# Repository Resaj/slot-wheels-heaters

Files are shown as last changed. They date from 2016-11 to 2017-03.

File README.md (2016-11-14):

# Slot wheels heaters
Wheels heaters for slot cars or line-following robots.

Each wheel heater carries a thermistor and is composed of an array of 25 resistor in parallel. The value of each resistance is 470 Ohm and the supply is a lipo battery 2S. Changing this values may burn the heaters, so if you change the values be sure the power consume values are right.

<p align="center">
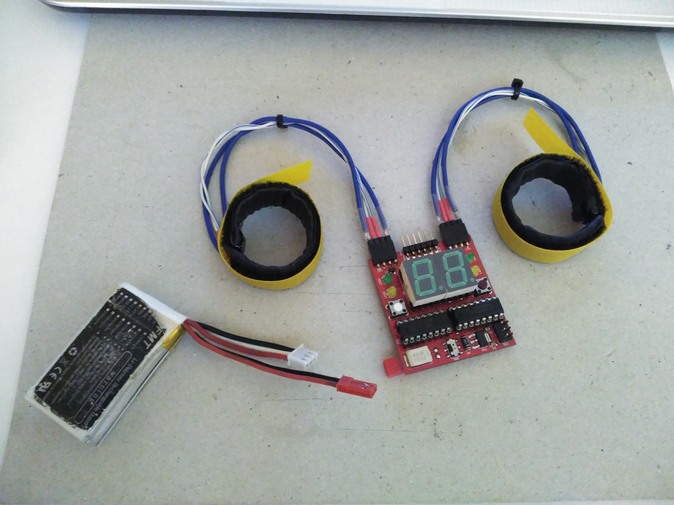
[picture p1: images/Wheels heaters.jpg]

</p>

## Author
[Rubén Espino San José](https://github.com/Resaj)

## License
<p align="center">

</p>

Todos estos productos están liberados mediante [Creative Commons Attribution-ShareAlike 4.0 International License](http://creativecommons.org/licenses/by-sa/4.0/).  
_All these products are released under [Creative Commons Attribution-ShareAlike 4.0 International License](http://creativecommons.org/licenses/by-sa/4.0/)._

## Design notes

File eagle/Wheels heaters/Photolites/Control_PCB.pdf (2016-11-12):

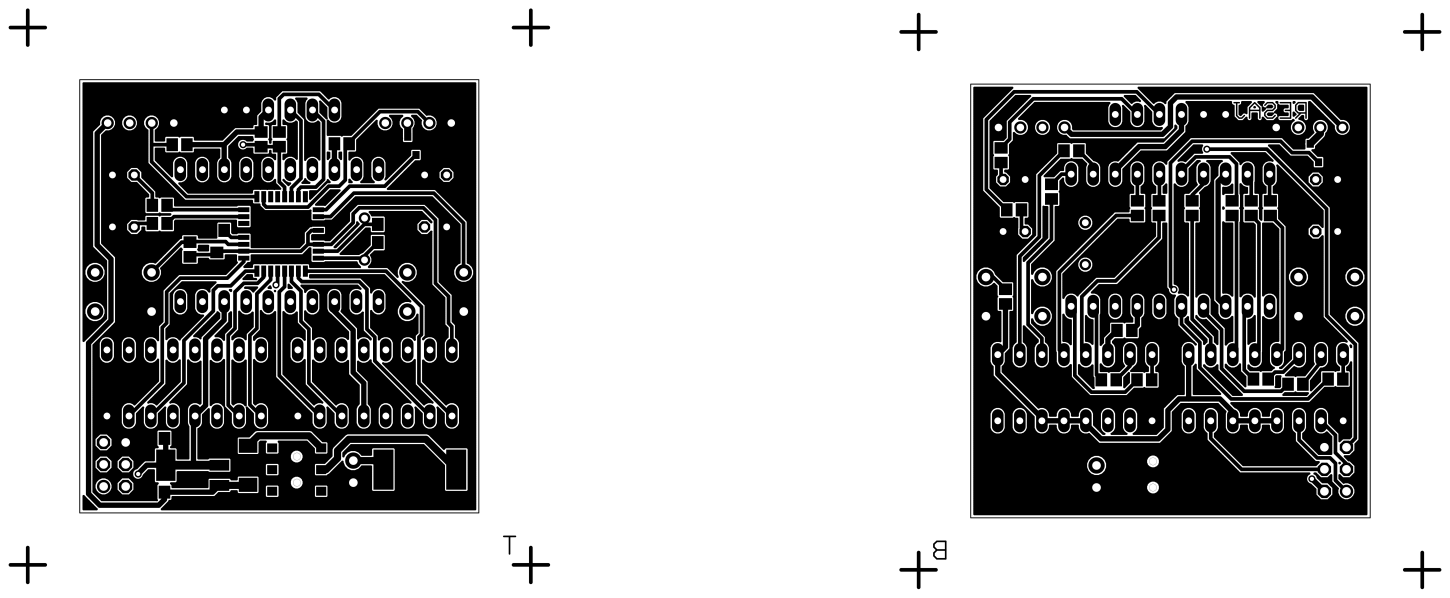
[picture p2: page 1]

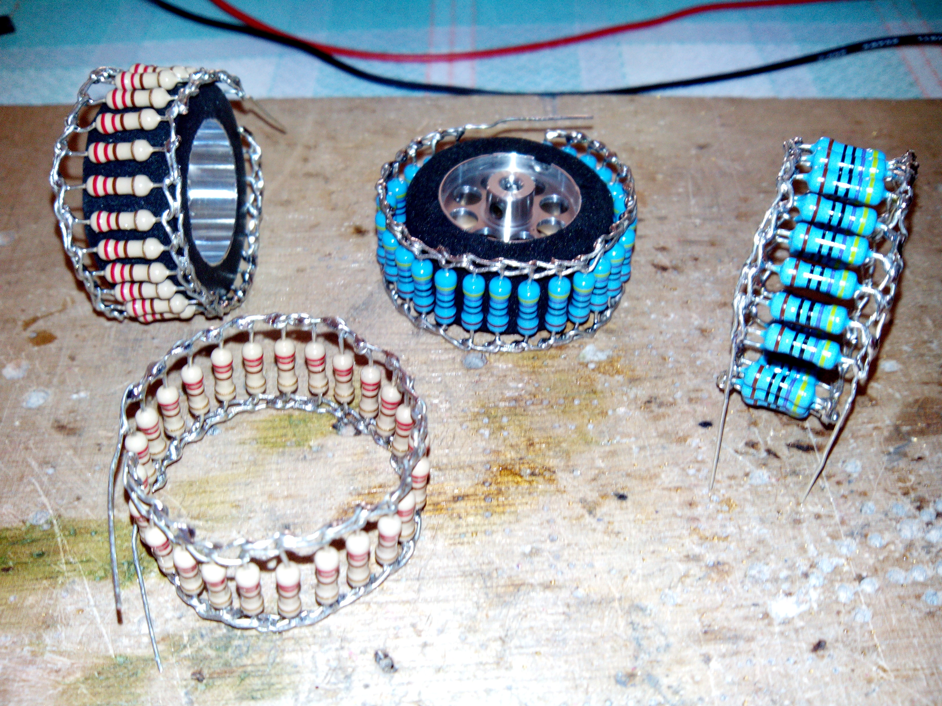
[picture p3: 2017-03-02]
images/IMG-20140706-WA0007.jpg

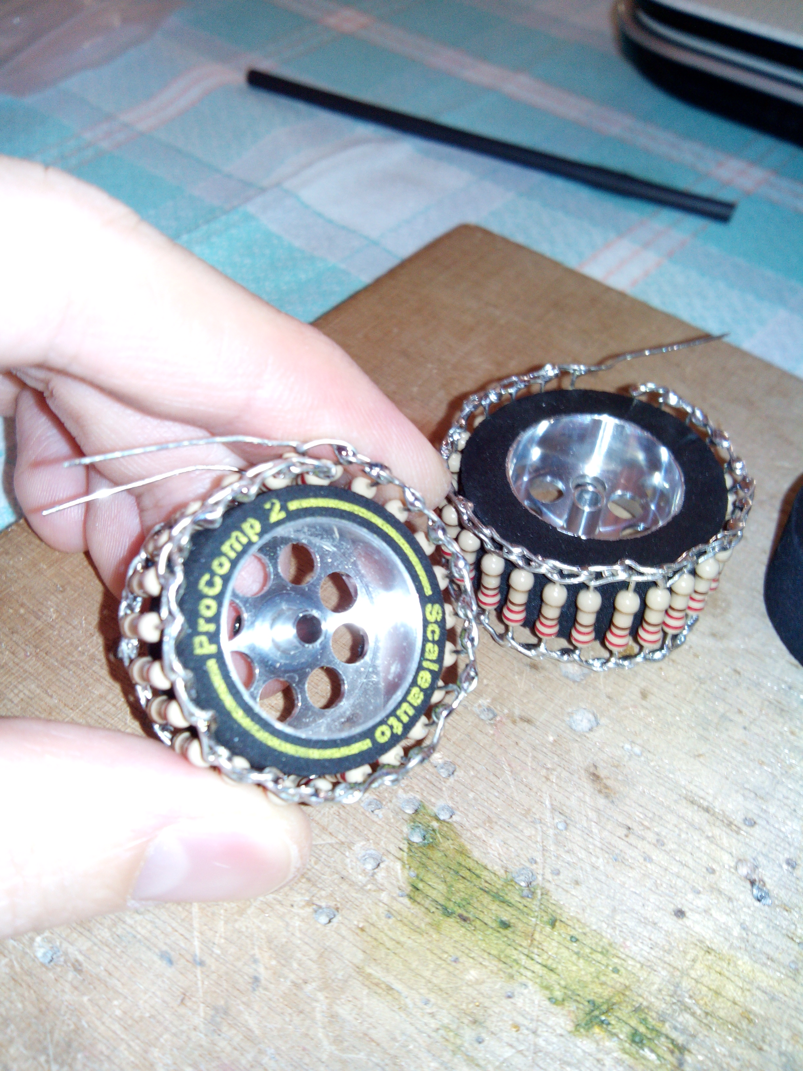
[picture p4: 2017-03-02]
images/IMG-20140706-WA0009.jpg

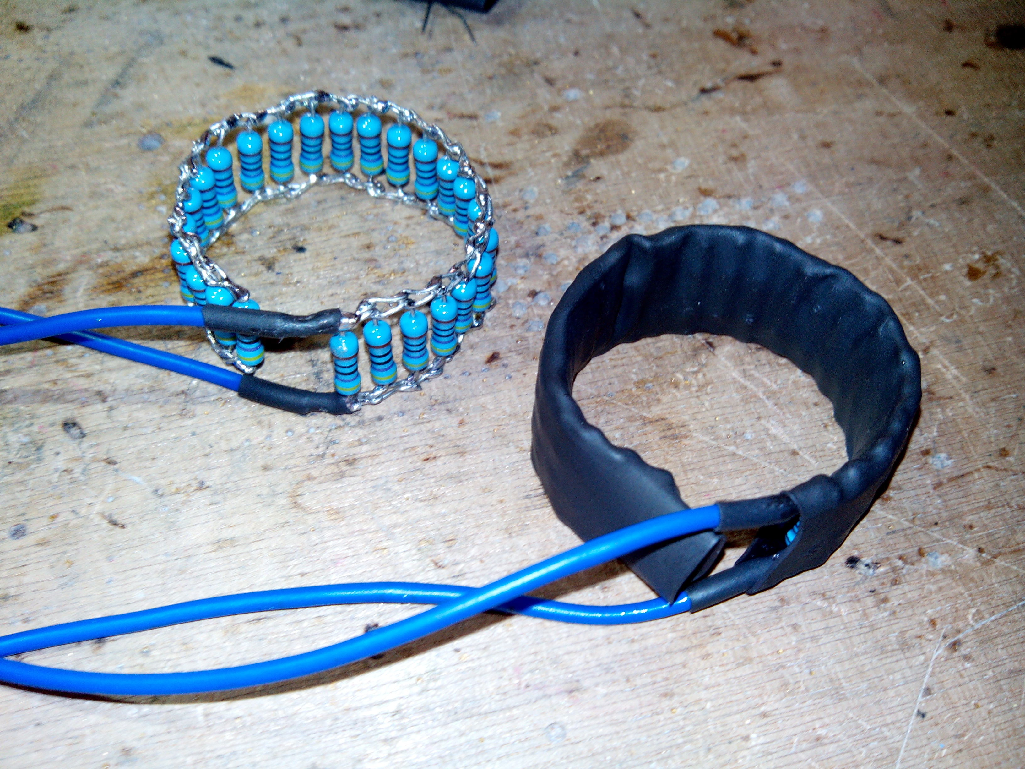
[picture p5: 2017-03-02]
images/IMG-20140706-WA0013.jpg

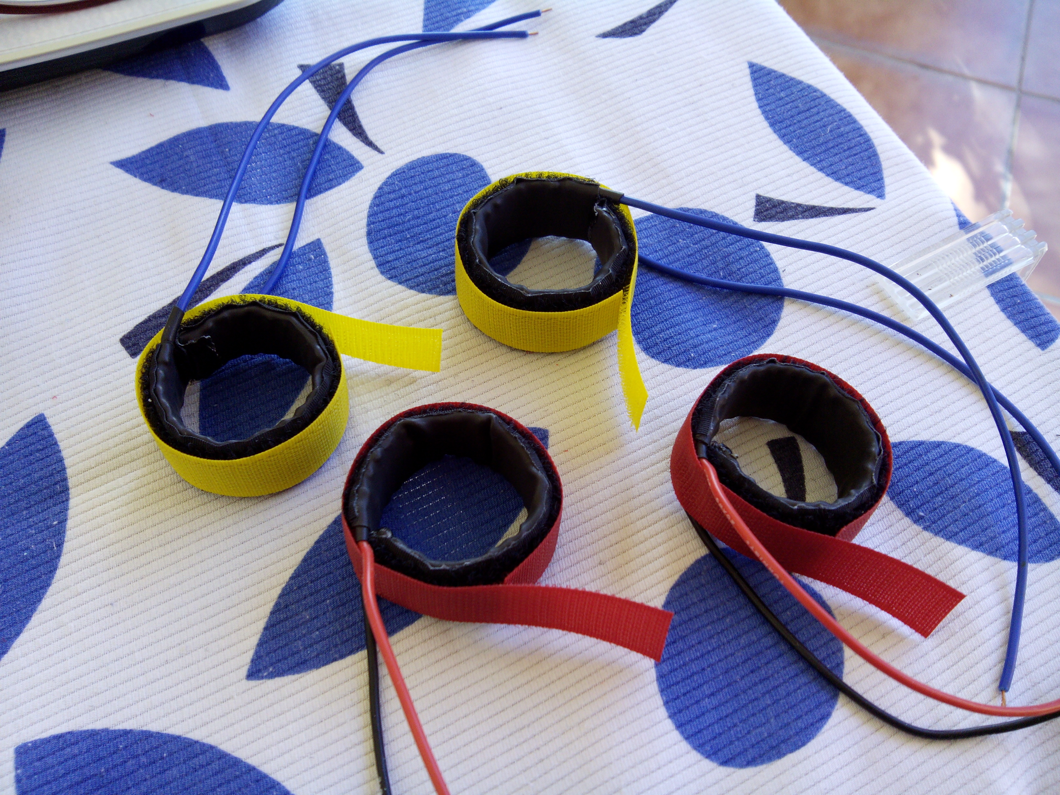
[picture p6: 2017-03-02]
images/IMG-20140808-WA0012.jpg

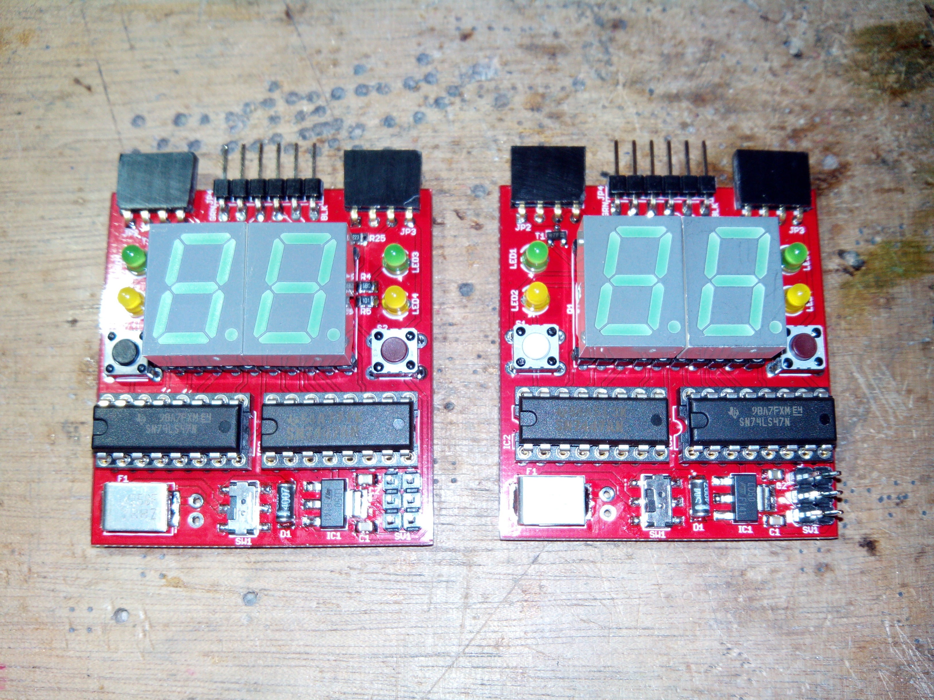
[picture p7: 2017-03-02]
images/IMG-20140826-WA0004.jpg

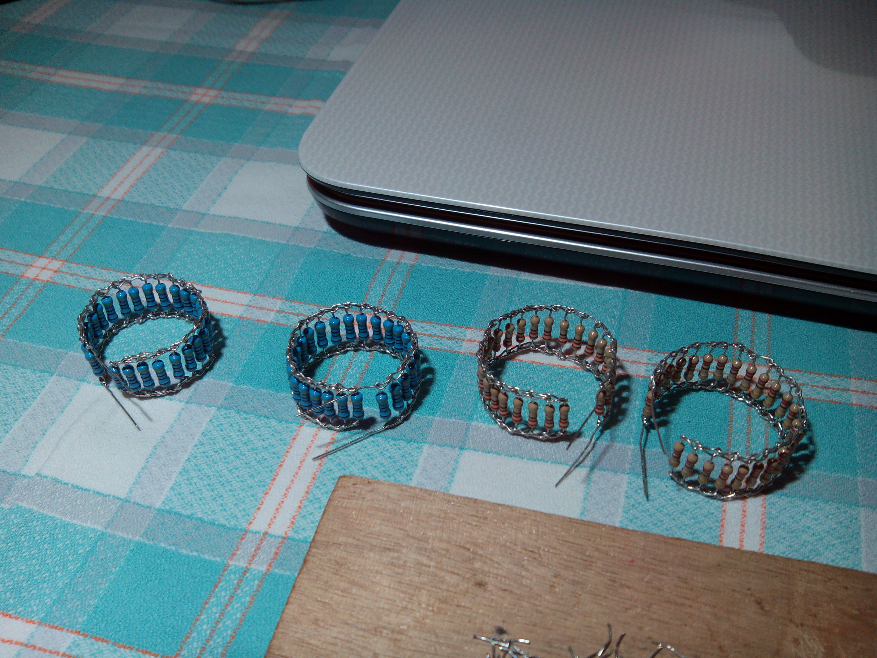
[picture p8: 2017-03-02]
images/IMG-20140706-WA0005.jpg

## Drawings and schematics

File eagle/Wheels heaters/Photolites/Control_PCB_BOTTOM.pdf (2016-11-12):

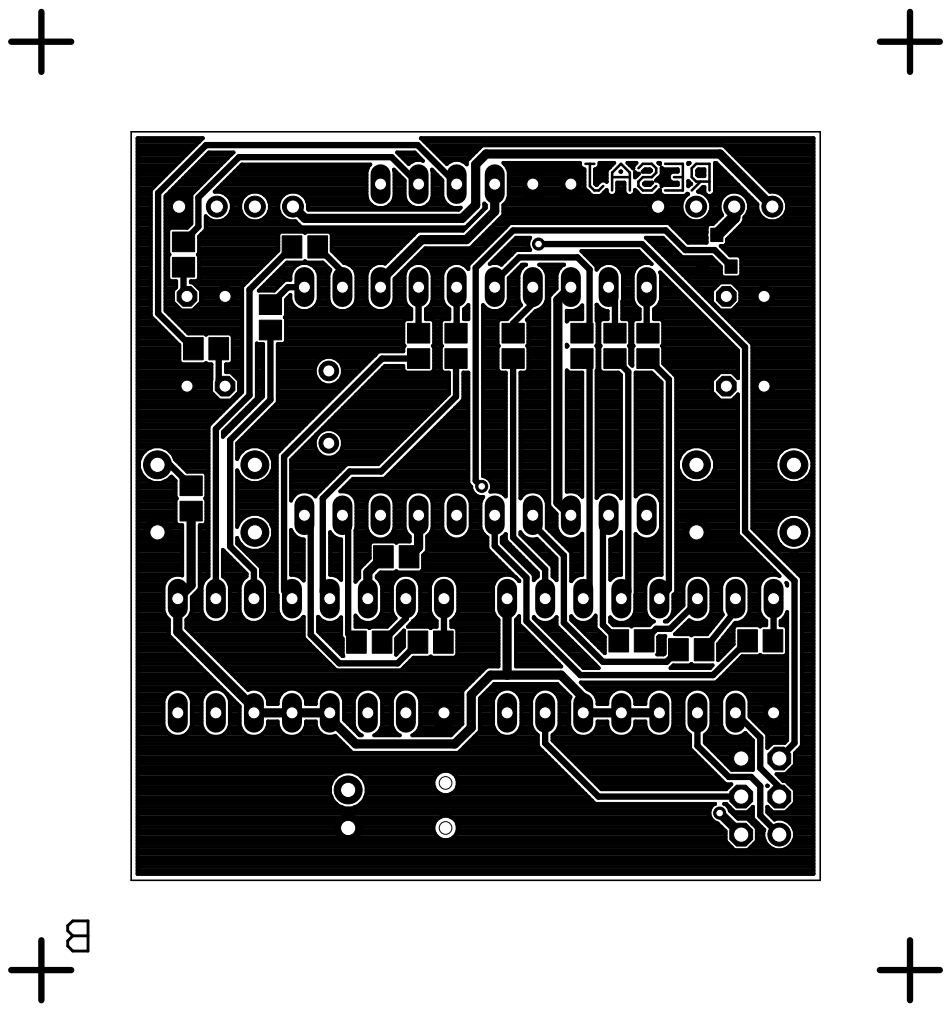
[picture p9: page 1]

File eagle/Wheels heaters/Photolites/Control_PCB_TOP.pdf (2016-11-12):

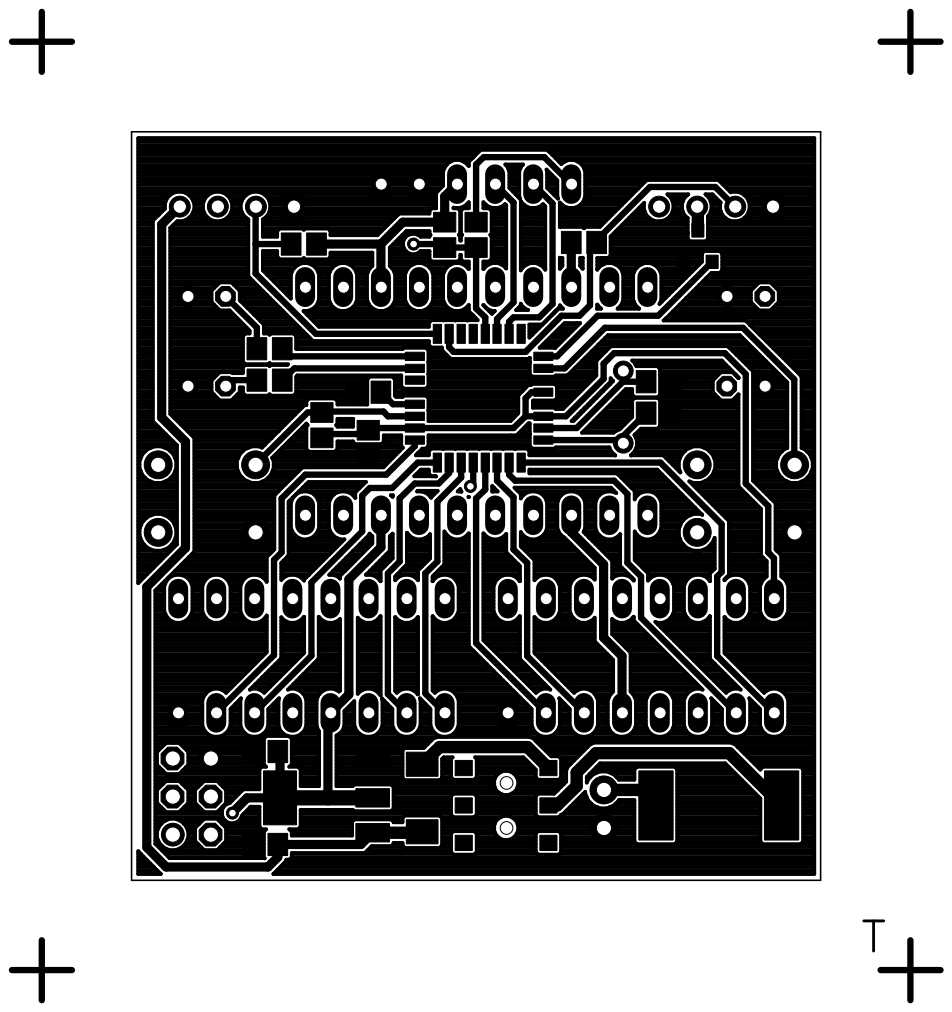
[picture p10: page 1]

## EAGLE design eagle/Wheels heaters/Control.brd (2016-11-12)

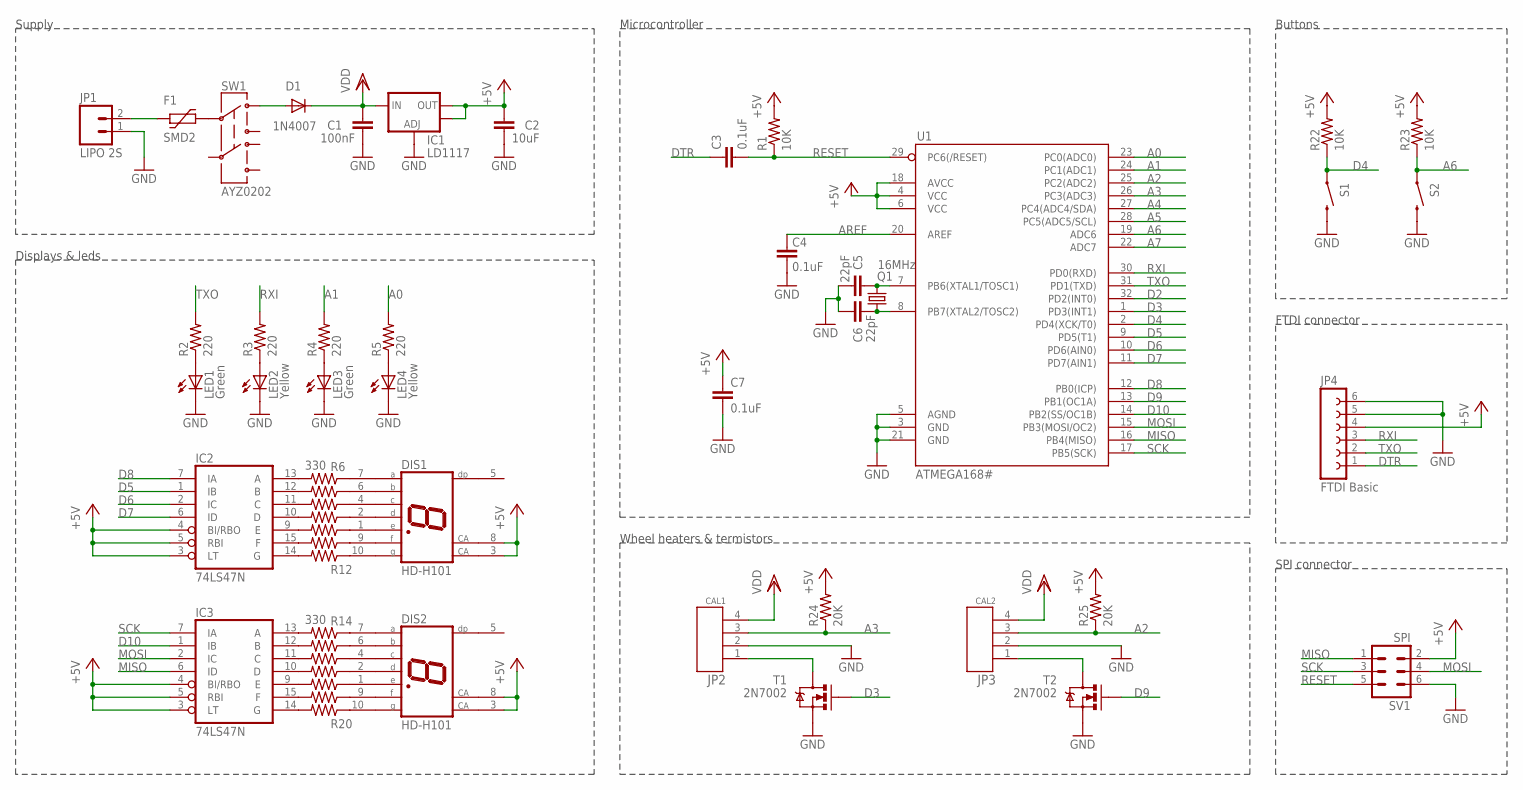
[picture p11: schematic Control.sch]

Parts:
C1: 100nF; C0805
C2: 10uF; C0805
C3, C4, C7: 0.1uF; C0805
C5, C6: 22pF; C0805
D1: 1N4007; SOD106-R
DIS1, DIS2: HD-H101; HDSP-M
F1: SMD2
IC1: LD1117; SOT223
IC2, IC3: 74LS47N; DIL16
JP1: LIPO 2S; 1X02
JP2: CAL1; 4_PINES_MACHO_TUMBADOS
JP3: CAL2; 4_PINES_MACHO_TUMBADOS
JP4: FTDI Basic; FE06W
LED1, LED3: Green; LED3MM
LED2, LED4: Yellow; LED3MM
Q1: 16MHz; HC49/S
R1, R22, R23: 10K; R0805
R2, R3, R4, R5: 220; R0805
R6, R7, R8, R9, R10, R11, R12, R14, R15, R16, R17, R18, R19, R20: 330; R0805
R24, R25: 20K; R0805
S1, S2: SWITCH-MOMENTARY-2PTH; TACTILE-PTH
SV1: SPI; MA03-2
SW1: AYZ0202
T1, T2: 2N7002; SOT23-3
U1: ATMEGA168#; TQFP32-08

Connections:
+5V: C2.1, C7.1, DIS1.3 (CA), DIS1.8 (CA), DIS2.3 (CA), DIS2.8 (CA), IC1.2 (OUT), IC1.4 (OUT), IC2.3 (LT), IC2.4 (BI/RBO), IC2.5 (RBI), IC2.16 (VCC), IC3.3 (LT), IC3.4 (BI/RBO), IC3.5 (RBI), IC3.16 (VCC), JP4.4, R1.2, R22.2, R23.2, R24.2, R25.2, SV1.2, U1.4 (VCC), U1.6 (VCC), U1.18 (AVCC)
A0: R5.2, U1.23 (PC0(ADC0))
A1: R4.2, U1.24 (PC1(ADC1))
A2: JP3.3, R25.1, U1.25 (PC2(ADC2))
A3: JP2.3, R24.1, U1.26 (PC3(ADC3))
A4: U1.27 (PC4(ADC4/SDA))
A5: U1.28 (PC5(ADC5/SCL))
A6: R23.1, S2.1, U1.19 (ADC6)
A7: U1.22 (ADC7)
AREF: C4.2, U1.20 (AREF)
D2: U1.32 (PD2(INT0))
D3: T1.1 (G), U1.1 (PD3(INT1))
D4: R22.1, S1.1, U1.2 (PD4(XCK/T0))
D5: IC2.1 (IB), U1.9 (PD5(T1))
D6: IC2.2 (IC), U1.10 (PD6(AIN0))
D7: IC2.6 (ID), U1.11 (PD7(AIN1))
D8: IC2.7 (IA), U1.12 (PB0(ICP))
D9: T2.1 (G), U1.13 (PB1(OC1A))
D10: IC3.1 (IB), U1.14 (PB2(SS/OC1B))
DTR: C3.1, JP4.1
GND: C1.1, C2.2, C4.1, C5.1, C6.1, C7.2, IC1.1 (ADJ), IC2.8 (GND), IC3.8 (GND), JP1.1, JP2.2, JP3.2, JP4.5, JP4.6, LED1.K (C), LED2.K (C), LED3.K (C), LED4.K (C), S1.3 (2), S2.3 (2), SV1.6, T1.2 (S), T2.2 (S), U1.3 (GND), U1.5 (AGND), U1.21 (GND)
MISO: IC3.6 (ID), SV1.1, U1.16 (PB4(MISO))
MOSI: IC3.2 (IC), SV1.4, U1.15 (PB3(MOSI/OC2))
unnamed: C6.2, Q1.2, U1.8 (PB7(XTAL2/TOSC2))
unnamed: C5.2, Q1.1, U1.7 (PB6(XTAL1/TOSC1))
unnamed: JP2.1, T1.3 (D)
unnamed: JP3.1, T2.3 (D)
unnamed: LED2.A, R3.1
unnamed: LED3.A, R4.1
unnamed: D1.A, SW1.3 (1)
unnamed: F1.P$2 (2), SW1.2
unnamed: F1.P$1 (1), JP1.2
unnamed: LED4.A, R5.1
unnamed: LED1.A, R2.1
unnamed: IC2.13 (A), R6.2
unnamed: DIS1.7 (A), R6.1
unnamed: IC2.12 (B), R7.2
unnamed: DIS1.6 (B), R7.1
unnamed: IC2.11 (C), R8.2
unnamed: DIS1.4 (C), R8.1
unnamed: IC2.10 (D), R9.2
unnamed: DIS1.2 (D), R9.1
unnamed: IC2.9 (E), R10.2
unnamed: DIS1.1 (E), R10.1
unnamed: IC2.15 (F), R11.2
unnamed: DIS1.9 (F), R11.1
unnamed: IC2.14 (G), R12.2
unnamed: DIS1.10 (G), R12.1
unnamed: IC3.13 (A), R14.2
unnamed: DIS2.7 (A), R14.1
unnamed: IC3.12 (B), R15.2
unnamed: DIS2.6 (B), R15.1
unnamed: IC3.11 (C), R16.2
unnamed: DIS2.4 (C), R16.1
unnamed: IC3.10 (D), R17.2
unnamed: DIS2.2 (D), R17.1
unnamed: IC3.9 (E), R18.2
unnamed: DIS2.1 (E), R18.1
unnamed: IC3.15 (F), R19.2
unnamed: DIS2.9 (F), R19.1
unnamed: IC3.14 (G), R20.2
unnamed: DIS2.10 (G), R20.1
RESET: C3.2, R1.1, SV1.5, U1.29 (PC6(/RESET))
RXI: JP4.3, R3.2, U1.30 (PD0(RXD))
SCK: IC3.7 (IA), SV1.3, U1.17 (PB5(SCK))
TXO: JP4.2, R2.2, U1.31 (PD1(TXD))
VDD: C1.2, D1.C, IC1.3 (IN), JP2.4, JP3.4

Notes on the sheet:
FTDI connector
Microcontroller
Displays & leds
Wheel heaters & termistors
Supply
Buttons
SPI connector

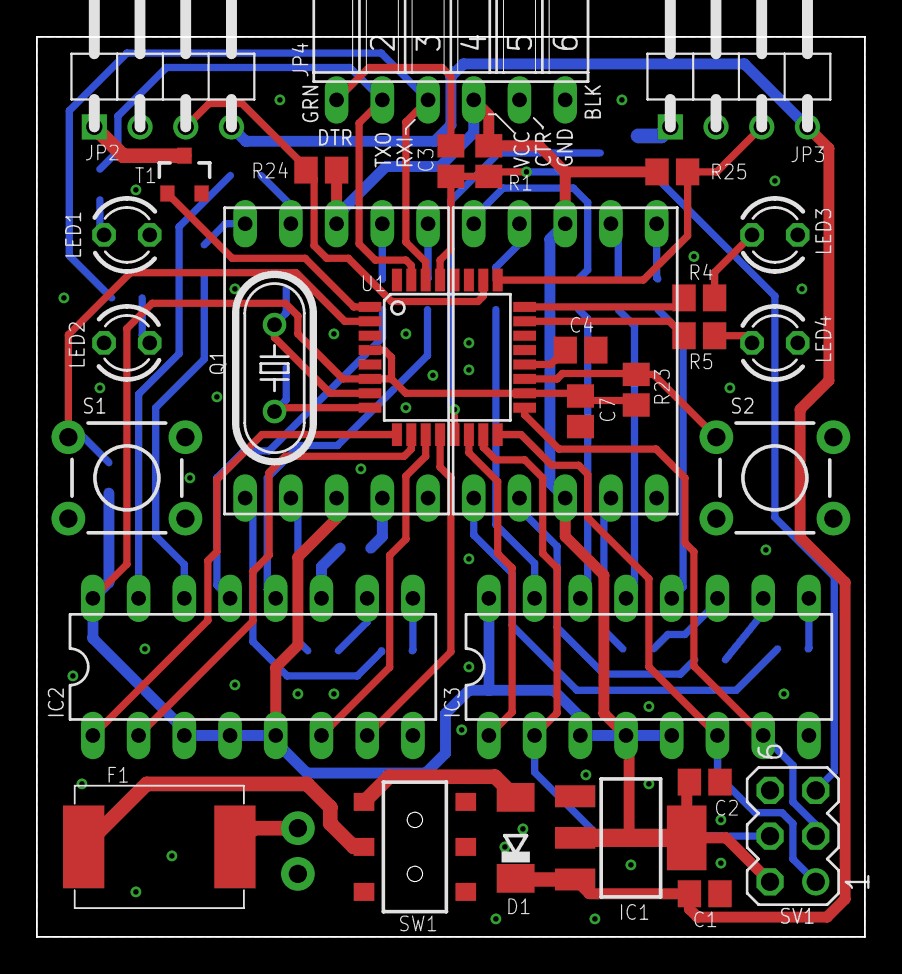
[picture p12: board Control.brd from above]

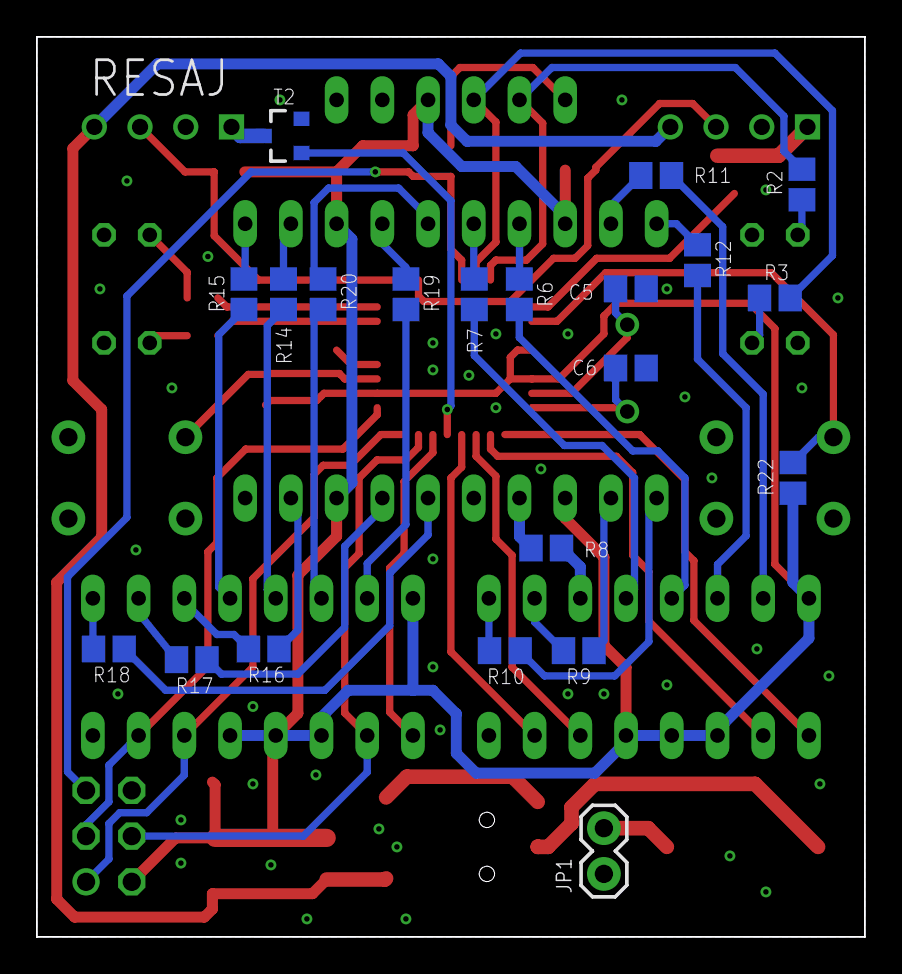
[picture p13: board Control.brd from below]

Board: 2 copper layers, 46.0 x 50.0 mm, 53 parts (21 on the bottom side), 63 nets.

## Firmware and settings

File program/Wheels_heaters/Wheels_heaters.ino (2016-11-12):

//#define SERIAL_ENABLE

int period = 10; // ms
int cont = 0;
int cont2 = 0;
int cont3 = 0;
int state = 0;

const int button_L = 4;
const int button_R = A6;
int button_L_State = 0;
int button_R_State = 0;
int button_L_State_ant = 0;
int button_R_State_ant = 0;

const int led_L_green =  1;
const int led_L_yellow =  0;
const int led_R_green =  A1;
const int led_R_yellow =  A0;

const int display1_A =  8;
const int display1_B =  5;
const int display1_C =  6;
const int display1_D =  7;
const int display2_A =  13;
const int display2_B =  10;
const int display2_C =  11;
const int display2_D =  12;

const int heater_L = 3;
const int heater_R = 9;

const int Tsensor_L = A3;
const int Tsensor_R = A2;
float bit_T_L = 0, bit_T_R = 0;
float T_L = 0, T_R = 0;
int T = 0;
int T_min = 0;
int T_max = 80;
float p_L = 0, p_R = 0;
float last_p_L = 0, last_p_R = 0;
float i_L = 0, i_R = 0;
float limit_int = 180;
float d_L = 0, d_R = 0;
float kp = 1000;
float ki = 0;
float kd = 0;
float controlT_L = 0;
float controlT_R = 0;
float Pmax = 255; // Máximum PWM output for transistors (between 0 & 255)

const int OVERSAMPLENR = 3;

const float temptable[][2] = {
   {1, 713},
   {17, 300},
   {20, 290},
   {23, 280},
   {27, 270},
   {31, 260},
   {37, 250},
   {43, 240},
   {51, 230},
   {61, 220},
   {73, 210},
   {87, 200},
   {106, 190},
   {128, 180},
   {155, 170},
   {189, 160},
   {230, 150},
   {278, 140},
   {336, 130},
   {402, 120},
   {476, 110},
   {554, 100},
   {635, 90},
   {713, 80},
   {784, 70},
   {846, 60},
   {897, 50},
   {937, 40},
   {966, 30},
   {986, 20},
   {1000, 10},
   {1010, 0}
};

void setup() {
  pinMode(button_L, INPUT);      
//  pinMode(button_R, INPUT);  // analog read of button_R

#ifndef SERIAL_ENABLE
  pinMode(led_L_green, OUTPUT);
  pinMode(led_L_yellow, OUTPUT);
  pinMode(led_R_green, OUTPUT);
  pinMode(led_R_yellow, OUTPUT);
#endif

  pinMode(display1_A, OUTPUT);
  pinMode(display1_B, OUTPUT);
  pinMode(display1_C, OUTPUT);
  pinMode(display1_D, OUTPUT);
  pinMode(display2_A, OUTPUT);
  pinMode(display2_B, OUTPUT);
  pinMode(display2_C, OUTPUT);
  pinMode(display2_D, OUTPUT);

#ifdef SERIAL_ENABLE
  Serial.begin(9600); 
#endif
}

void loop() {
/******************************* BUTTONS READING *******************************/
  button_L_State = digitalRead(button_L);
  button_R_State = analogRead(button_R);
  if(button_R_State > 512)
    button_R_State = HIGH;
  else
    button_R_State = LOW;

  if(button_L_State == LOW && button_L_State_ant == HIGH && T > T_min)
  {
    T = T - 5;
    state = 1;
    cont = 0;
  }
  else if(button_R_State == LOW && button_R_State_ant == HIGH && T < T_max)
  {
    T = T + 5;
    state = 1;
    cont = 0;
  }
  
  button_L_State_ant = button_L_State;
  button_R_State_ant = button_R_State;

  if(cont3 >= 500)
  {
/******************************* READING AND AVERAGE TEMPERATURE *******************************/
    bit_T_L = 0;
    bit_T_R = 0;
    for(int i=0; i<OVERSAMPLENR; i++)
    {
      bit_T_L = bit_T_L + analogRead(Tsensor_L);
      bit_T_R = bit_T_R + analogRead(Tsensor_R);
    }
    bit_T_L = bit_T_L/OVERSAMPLENR;
    bit_T_R = bit_T_R/OVERSAMPLENR;

    T_L = bit2deg(bit_T_L);
    T_R = bit2deg(bit_T_R);
  
/******************************* TEMPERATURE PID *******************************/
    p_L = T - T_L;
    p_R = T - T_R;
  
    d_L = p_L - last_p_L;
    d_R = p_R - last_p_R;
  
    i_L = i_L + p_L;
    i_R = i_R + p_R;
    
    if(i_L > limit_int)
      i_L = limit_int;
    if(i_R > limit_int)
      i_R = limit_int;
  
    last_p_L = p_L;
    last_p_R = p_R;
    
    controlT_L = p_L * kp + i_L * ki + d_L * kd;
    controlT_R = p_R * kp + i_R * ki + d_R * kd;
  
    if(controlT_L > Pmax)
      controlT_L = Pmax;
    else if(controlT_L < 0)
      controlT_L = 0;
    if(controlT_R > Pmax)
      controlT_R = Pmax;
    else if(controlT_R < 0)
      controlT_R = 0;
  
    analogWrite(heater_L, controlT_L);           
    analogWrite(heater_R, controlT_R);
  }

/******************************* LEDS AND DISPLAY *******************************/
  if(abs(T - T_L) < 2)
    writeLED(led_L_green, HIGH);
  else
    writeLED(led_L_green, LOW);
  if(abs(T - T_R) < 2)
    writeLED(led_R_green, HIGH);
  else
    writeLED(led_R_green, LOW);

  if(state == 0)
  {
    if(cont < 1000)
    {
      writeLED(led_L_yellow, LOW);
      writeLED(led_R_yellow, LOW);
      display_T(int(T));
    }
    else if(cont < 2000)
    {
      writeLED(led_L_yellow, HIGH);
      writeLED(led_R_yellow, LOW);
      display_T(int(T_L));
    }
    else
    {
      writeLED(led_L_yellow, LOW);
      writeLED(led_R_yellow, HIGH);
      display_T(int(T_R));
      
      if(cont >= 3000)
        cont = 0;
    }
  }
  else if(state == 1)
  {
    writeLED(led_L_yellow, HIGH);
    writeLED(led_R_yellow, HIGH);
    display_T(int(T));
    
    if(cont >= 1000)
    {
      state = 0;
      cont = 0;
    }
  }

/******************************* SERIAL PORT DATA *******************************/
#ifdef SERIAL_ENABLE
  if(cont2 >= 1000) {
    Serial.print("CONSIGNA: ");                       
    Serial.print(T);
    Serial.print(" / IZQ: ");  
    Serial.print(T_L);
    Serial.print(" / DER: ");  
    Serial.println(T_R);
    
    cont2 = 0;
  }
#endif
  
/******************************* COUNTERS UPDATE *******************************/
  cont += period;
  cont2 += period;
  cont3 += period;
  delay(period);                     
}

float bit2deg(float value) {
  float Temp = 0;
  int i = 0;
  
  for(i = 0; temptable[i][0] < value; i++);

  Temp = (temptable[i-1][1] - temptable[i][1]) / (temptable[i-1][0] - temptable[i][0]) * value
    + temptable[i][1] - (temptable[i-1][1] - temptable[i][1]) / (temptable[i-1][0] - temptable[i][0]) * temptable[i][0];

  return Temp;
}

void writeLED(int led, int value)
{
#ifndef SERIAL_ENABLE
  digitalWrite(led, value);
#endif
}

void display_T(int temp) {
  int decenas = 0, unidades = 0;
  int aux = 0;
  
  decenas = temp / 10;
  unidades = temp - decenas * 10;
  
  if(decenas - 8 >= 0)
  {
    digitalWrite(display1_D, HIGH);
    aux = decenas - 8;
  }
  else
  {
    digitalWrite(display1_D, LOW);
    aux = decenas;
  }
  
  if(aux - 4 >= 0)
  {
    digitalWrite(display1_C, HIGH);
    aux = aux - 4;
  }
  else
    digitalWrite(display1_C, LOW);
    
  if(aux - 2 >= 0)
  {
    digitalWrite(display1_B, HIGH);
    aux = aux - 2;
  }
  else
    digitalWrite(display1_B, LOW);

  if(aux - 1 >= 0)
  {
    digitalWrite(display1_A, HIGH);
    aux = aux - 1;
  }
  else
    digitalWrite(display1_A, LOW);

  if(unidades - 8 >= 0)
  {
    digitalWrite(display2_D, HIGH);
    aux = unidades - 8;
  }
  else
  {
    digitalWrite(display2_D, LOW);
    aux = unidades;
  }
  
  if(aux - 4 >= 0)
  {
    digitalWrite(display2_C, HIGH);
    aux = aux - 4;
  }
  else
    digitalWrite(display2_C, LOW);
    
  if(aux - 2 >= 0)
  {
    digitalWrite(display2_B, HIGH);
    aux = aux - 2;
  }
  else
    digitalWrite(display2_B, LOW);

  if(aux - 1 >= 0)
  {
    digitalWrite(display2_A, HIGH);
    aux = aux - 1;
  }
  else
    digitalWrite(display2_A, LOW);
}
